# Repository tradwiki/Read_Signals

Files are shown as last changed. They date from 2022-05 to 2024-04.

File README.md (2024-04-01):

# rythm-visuals-plank-5
Podorythmic drawplank setup

rythm-visuals-plank-5 is an adaptation of [rythm-visuals-plank-4](https://github.com/tradwiki/rythm-visuals-plank-4). 
It transforms the reading of sensors embedded in a plank and transforms it into a midi and OSC signal to generate visuals.
This project showcases the use of analog piezo sensors and FSR sensors sending MIDI signals through a custom circuit that are translated in OSC through python and sent to a processing program to generate visuals.

## Getting started
* Connect the plank to the computer via USB.
* Run the script [analyse_signal.py](https://github.com/tradwiki/rythm-visuals-plank-5/blob/main/Analyse_signal/Analyse_signal.py)
* Run Drawplank 2.0 script.

## Planche 5 - Read_Signals (Arduino Script)
[Planche_5_-_Read_Signals](https://github.com/tradwiki/rythm-visuals-plank-5/tree/main/Planche_5_-_Read_Signals) is designed to be uploaded to a Teensy (3.6) controller via the arduino IDE (see [Teensyduino documentation](https://www.pjrc.com/teensy/teensyduino.html)). The script sends data through the serial port to notify of an analog value spike on specified pins when the polled value is above the baseline by a certain threshold. The baseline is averaged over the previous readings while they remain below threshold. The threshold is adjusted based on signal stability to allow for more sensitive readings with more stable sensors. The script also sends and/or receives MIDI signals across USB using Teensy built-in support (see [Teensy USB MIDI documentation](https://www.pjrc.com/teensy/td_midi.html)).

<code style="color: Darkorange;">The arduino script is downloaded once in the Teensy of the plank.</code> 
### Configuration
Modify [/Planche_5_-_Read_Signals/config.h](https://github.com/tradwiki/rythm-visuals-plank-5/blob/main/Planche_5_-_Read_Signals/config.h) to modify thresholds, delays, notes, pins, debug.
#### Considerations
* Midi pin values are specific to the circuit design as presented
* Analyse_Signal configurations are dependant of MIDI note configurations
* Drawplank 2.0 configurations are dependant of the Analyse_Signal configurations 
* Thresholds, baselines and delays are the result of physical tests on the plank and may vary for specific constructions

## Analyse Signal (Python script)
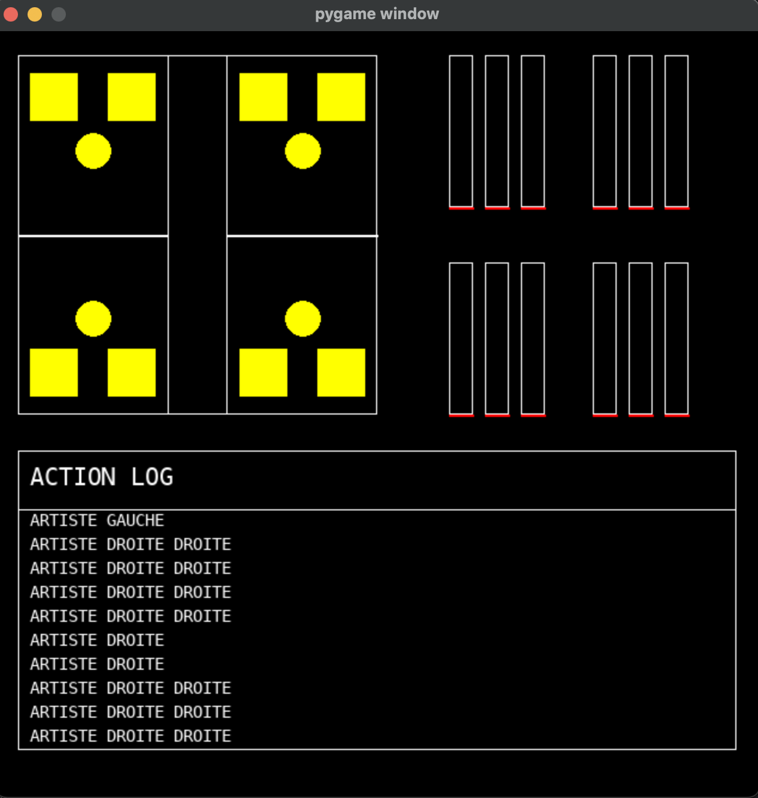
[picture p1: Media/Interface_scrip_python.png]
Analyse_signal screen capture


The python script translates MIDI signals coming from the plank to OSC signals. It interpretates different spikes and repetitions based on the signal received from the serial port as well as bpm.
The python script offers a visual interface of the incoming signals for troubleshooting through the pygame librairie.
### Configuration
[python_script/Sensor.py](https://github.com/tradwiki/rythm-visuals-plank-5/blob/main/Analyse_signal/Sensor.py) defines the OSC signal parameters as well as the sensor names.
By default, data is sent to the IP address 10.10.30.44 through port 5005.
#### Libraries for python
The installation of the following librairies is required for the python script.
* [python-osc](https://pypi.org/project/python-osc)
* [pygame](https://www.pygame.org/wiki/GettingStarted)

## Drawplank 2.0
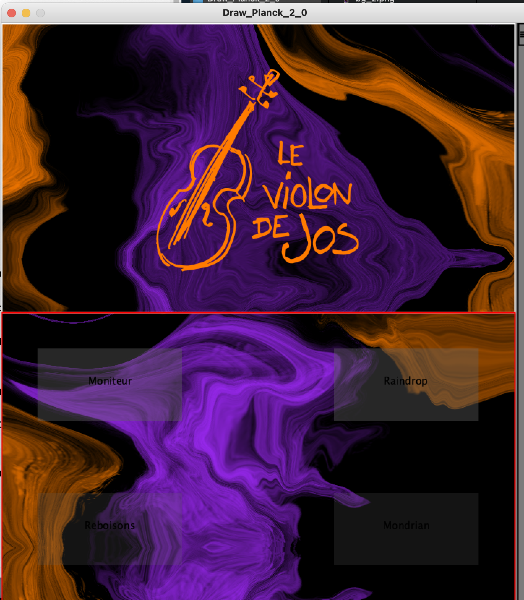
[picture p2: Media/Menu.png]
Drawplank screen capture

[Drawplank 2.0](https://github.com/tradwiki/rythm-visuals-plank-5/tree/main/DrawPlanck-2.0) was developped with the purpose of being used for video mapping through [Splash](https://sat.qc.ca/fr/splash/).
The program offers different modes of visual rendering of the plank's signal. 

<code style="color: Darkorange;">In order to use Drawplank 2.0, the python script must be running.</code> 
### Modes
Drawplank 2.0 offers 4 different modes
* Monitor
* Mondrian
* Raindrop
* Reboisons
### Use
* To select mode, the corresponding pad must be held.
* To exit a selected mode, the upper left pad must be held down.

## Device
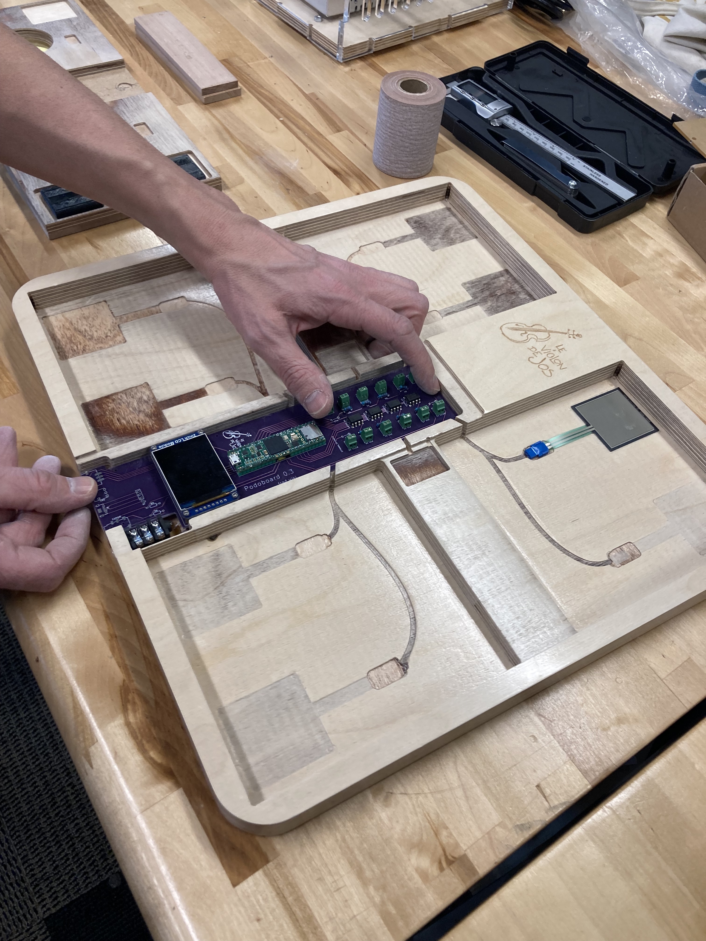
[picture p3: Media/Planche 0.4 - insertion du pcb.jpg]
Insertion of the pcb in the plank


A custom pcb was printed for this project. The circuit uses 8 FSR sensors and 5 Piezo sensors.
One piezo sensor is used as a surface microphone and does not produce a digital signal.
The plank was cut using a CNC.
Further discription is available in the [/circuit](https://github.com/tradwiki/rythm-visuals-plank-5/tree/main/Circuit) folder.

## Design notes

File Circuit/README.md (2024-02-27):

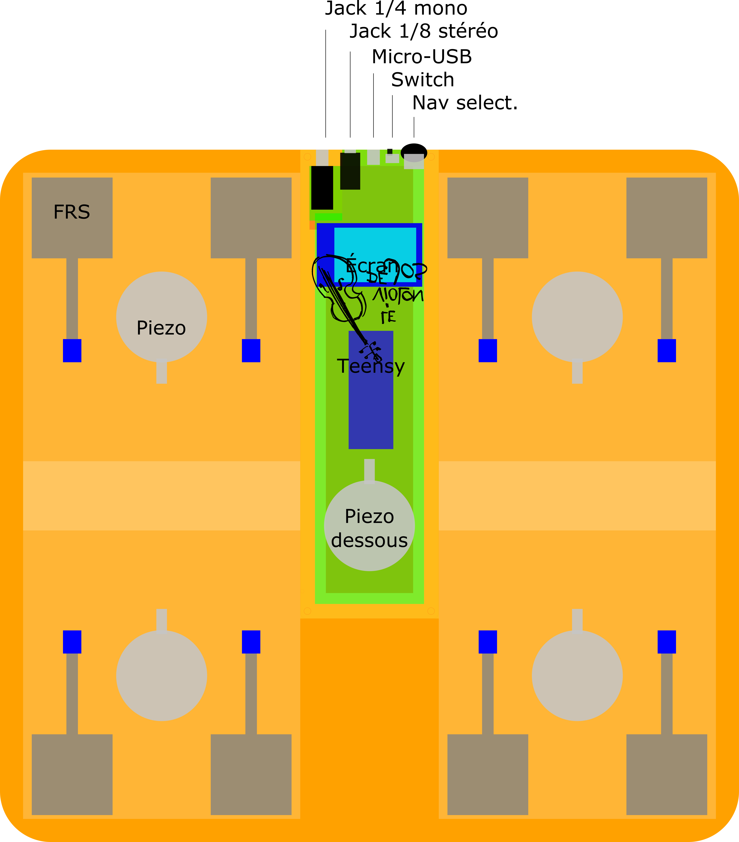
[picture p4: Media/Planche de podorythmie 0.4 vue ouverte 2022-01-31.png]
Plan planche de podorythmie


# Podoboard 0.3
The podoboard 0.3 is a custom printed pcb board that collects signals of 8 FSR sensors and 5 piezo sensors which were embedded in a Plank. The gerber files can be found in the [podoboard gerber](https://github.com/tradwiki/rythm-visuals-plank-5/tree/main/Circuit/podoboard%20gerber) folder.

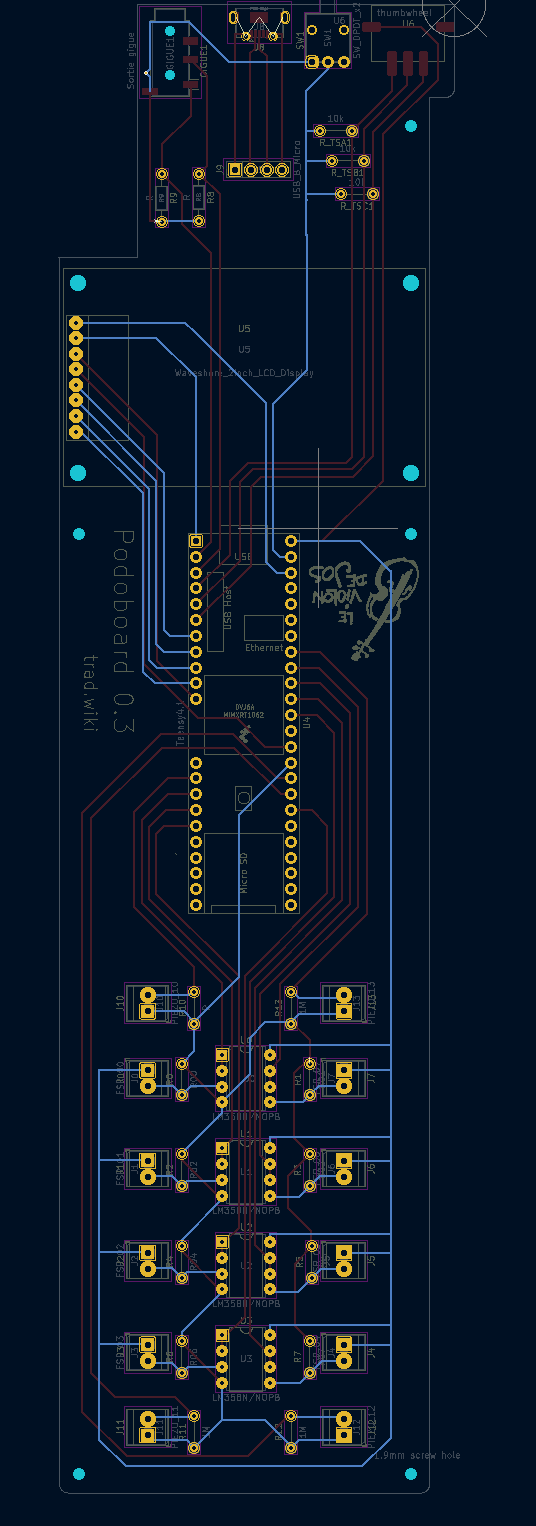
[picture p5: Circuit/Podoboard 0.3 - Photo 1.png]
Podoboard 0.3


### List of parts
* [Teensy 3.6](https://www.pjrc.com/store/teensy36.html)
* [FSR Sensor](https://www.sparkfun.com/products/9376) * 8
* [Piezo Sensor](https://www.digikey.ca/en/products/detail/7BB-35-3C/490-7716-ND/4358156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)
* [LM358P Amplifier](https://www.digikey.ca/en/products/detail/LM358P/296-1395-5-ND/277042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) * 5
* [SBL5100 Schottky diode](https://www.digikey.ca/en/products/detail/SBL5100TA/1655-1527-1-ND/6022972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) * 8
* 5 kOhm Resistor * 5
* [FSR Amplhenol 2.54 mm connectors](http://d.digikey.com/dc/mn-w0iJh4uEE_bUitNCuXsaMqkw5UctQEQXQivOAnBOQnPRuGl71VF0ow_3mKzthT57jIPNeUOJXfLLS_QA7CxnVzpsYQBHfvLHpVdyEOlp4vdeCMniPBPFYAcDw0YV2FBJ9wsG8VWLjt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) * 8
* [Screw terminals](https://www.digikey.ca/en/products/detail/OSTVN02A150/ED10561-ND/1588862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) *   13

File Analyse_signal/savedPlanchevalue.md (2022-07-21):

color C1 = color(150, 30, 0);
int NUM_FSR = 8;
int NUM_PIEZO = 4;
int SENSOR_STORED_READ_SIZE = 400;

int FSR_STATE_THRESHOLD = 10;
int PIEZO_STATE_THRESHOLD = 10;
int PLEIN_PIED_THRESHOLD = 10;
int PLEIN_PIED_MEAN = 50;
int FSR_MAX_TIME = 3000;
int PIEZO_MAX_TIME = 3000;

int[] FSR_NOTES = {74, 76, 78, 79, 81, 83, 85, 86};
int[] PIEZO_NOTES = {100, 101, 102, 103};

//int FSR_GRAPH_WIDTH = 350;
int MAX_BAR_TIME = 3000;

class Sensor {
  int id, note;
  String type;
  boolean state;
  int read, max;
  PFont font;
  int timer;
  int stateThreshold, maxTime;
  int[] storedReads;
  int readIndex;

  Sensor(String type, int id, int note) {
    this.type = type;
    this.id = id;
    this.note = note;
    this.read = 0;
    this.state = false;
    this.font = createFont("Noto Serif", 14);
    this.storedReads = new int[SENSOR_STORED_READ_SIZE];
    this.readIndex = 0;

    if (type == "fsr") {
      this.stateThreshold = FSR_STATE_THRESHOLD;
      this.maxTime = FSR_MAX_TIME;
    } else {
      this.stateThreshold = PIEZO_STATE_THRESHOLD;
      this.maxTime = PIEZO_MAX_TIME;
    }
  }

  int getRead() {
    return this.read;
  }

  void advanceRead() {
    storedReads[readIndex] = read;
    readIndex = (readIndex + 1) % SENSOR_STORED_READ_SIZE;
  };

  void setRead(int r) {

  }
  
  void handleOSC(OscMessage theOscMessage){
    if (!(theOscMessage.addrPattern().equals(this.prevTap))) {
      this.prevTap = theOscMessage.addrPattern();

      int x, y;
      
      switch(prevTap) {
      case "/FSR/PG":
        x = int(random(0, screenWidth / 2));
        y = int(random(0, screenHeight / 2));
        break;
      case "/FSR/PD":
        x = int(random(screenWidth / 2, screenWidth));
        y = int(random(0, screenHeight / 2));
        break;
      case "/FSR/AG":
        x = int(random(0, screenWidth / 2));
        y = int(random(screenHeight/ 2, screenHeight));
        break;
      case "/FSR/AD":
        break;
      default:
      }
    }
  }

  void showGraph(int x, int y, float graphX, int w, int h) {
    noStroke();
    textFont(font);
    fill(255);
    text(type + id, x - 30, y + h);
    //noFill();
    //strokeWeight(2);
    fill(255);
    rectMode(CORNER);
    rect(x, y, w, h);
    float graphY;
    fill(C1);
    noStroke();

    for (int i = 0; i < readIndex; i++) {
      graphY = map(storedReads[i], 0, 127, 0, h - 5);
      rect(x + i * 2, y - 2 - graphY + h, 2, 2);
    }
  }

  void showGraph2(int x, int y, float graphX, int w, int h) {
    noStroke();
    fill(255);
    rectMode(CORNER);
    rect(x, y, SENSOR_STORED_READ_SIZE * 2, h);
    float graphY;
    fill(C1);
    noStroke();

    for (int i = 0; i < 400; i++) {
      graphY = map(storedReads[i], 0, 127, 0, h - 5);
      rect(x + i * 2, y - 2 - graphY + h, 2, graphY);
    }

    fill(C1);
    rect(x + readIndex * 2, y, 5, 35);
  }

  void showGraph3(int x, int y, float graphX, int w, int h) {
    noStroke();
    textFont(font);
    fill(255);
    text(type + id, x - 30, y + h);
    //noFill();
    //strokeWeight(2);
    fill(255);
    rectMode(CORNER);
    rect(x, y, SENSOR_STORED_READ_SIZE * 2, h);
    float graphY;
    fill(0, 123, 0);
    noStroke();

    for (int i = readIndex / 2; i < readIndex; i++) {
      graphY = map(storedReads[i], 0, 127, 0, h - 5);
      rect(x + i * 2, y - 2 - graphY + h, 2, graphY);
    }

    //fill(255, 255, 255);
    rect(x + readIndex * 2, y, 2, 70);
  }

  void showBar(int x, int y) {
    rectMode(CORNER);
    noStroke();
    fill(255);
    int size = 100;
    rect(x, y, 20, size);
    fill(0, 255, 0);
    float level = map(read, 0, 127, 0, size);
    rect(x, y - level + size, 20, level);
    stroke(255);
    //stroke(0);
    fill(C1);
    float mappedMax = map(max, 0, 127, 0, size);
    noStroke();
    rect(x, y - mappedMax + size, 20, 3);
    if (millis() - this.timer > maxTime && max > 1) {
      max = 1;
    }
  }

  void emptyStoreReads() {
    for (int i = 0; i < SENSOR_STORED_READ_SIZE; i++) {
      storedReads[i] = 0;
    }
  }
}

class Planche {
  //OscP5 oscP5;
  Sensor[] fsr;
  Sensor[] piezo;
  Sensor[] sGauche, sDroite;
  float graphX;
  boolean pauseGraph, pauseBar;
  float mean;
  PFont font;

  Planche() {
    //this.oscP5 = new OscP5(this, 1100);
    print(PFont.list());
    this.font = createFont("Noto Serif", 14);
    this.pauseGraph = false;
    this.pauseBar = false;
    this.fsr = new Sensor[NUM_FSR];
    this.piezo = new Sensor[NUM_PIEZO];
    this.sGauche = new Sensor[6];
    this.sDroite = new Sensor[6];
    this.mean = 0;

    for (int i = 0; i < NUM_FSR; i++) {
      fsr[i] = new Sensor("fsr", i, FSR_NOTES[i]);
    }

    for (int i = 0; i < NUM_PIEZO; i++) {
      piezo[i] = new Sensor("piezo", i, PIEZO_NOTES[i]);
    }

    for (int i = 0; i < 4; i++) {
      sGauche[i] = fsr[i];
      sDroite[i] = fsr[i + 4];
    }

    for (int i = 0; i < 2; i ++) {
      sGauche[i + 4] = piezo[i];
      sDroite[i + 4] = piezo[i + 2];
    }
  }

  void showGrid(int x, int y) {
    fill(255);
    textFont(font);
    textAlign(LEFT);
    //text("Senseurs actifs", x - 150, y - 160);
    rectMode(CENTER);
    stroke(255);
    noFill();
    rect(x, y, 300, 300);
    strokeWeight(2);
    stroke(255);
    noFill();
    rect(x - 75, y - 75, 150, 150);
    rect(x + 75, y - 75, 150, 150);
    rect(x - 75, y + 75, 150, 150);
    rect(x + 75, y + 75, 150, 150);

    for (int i = 0; i < fsr.length; i++) {

      float tempX = x - 185 + 70 * (i % 4 + 1);
      float tempY = y - 110;

      if ((i > 1 && i < 4) || (i > 5)) {
        tempX += 20;
      }

      if (i >= 4) {
        tempY = y + 110;
      }

      noStroke();
      fill(255);
      rect(tempX, tempY, 50, 50);
      fill(255, 255 - map(fsr[i].read, 0, 127, 0, 255), 0);
      rect(tempX, tempY, map(fsr[i].read, 0, 127, 0, 50), map(fsr[i].read, 0, 127, 0, 45));
    }

    for (int i = 0; i < piezo.length; i++) {
      float tempX = x - 80 + 160 * (i % 2);

      float tempY = y  - 50;

      if (i >= 2) {
        tempY = y + 50;
      }
      fill(255);
      ellipse(tempX, tempY, 50, 50);
      fill(255, 255 - map(piezo[i].read, 0, 127, 0, 255), 0);
      ellipse(tempX, tempY, map(piezo[i].read, 0, 127, 0, 50), map(piezo[i].read, 0, 127, 0, 50));
    }
    
        if (padComplet(fsr[0], fsr[1])) {
      fill(255, 255, 0);
      noStroke();
      rect(x - 75, y - 100, 130, 50);
      fill(0);
      textAlign(CENTER);
      text("Public cour", x - 75, y - 100);
    }

    if (padComplet(fsr[2], fsr[3])) {
      fill(255, 255, 0);
      noStroke();
      rect(x + 75, y - 100, 130, 50);
      fill(0);
      textAlign(CENTER);
      text("Public jardin", x + 75, y - 100);
    }

    if (padComplet(fsr[4], fsr[5])) {
      fill(255, 255, 0);
      noStroke();
      rect(x - 75, y + 100, 130, 50);
      fill(0);
      textAlign(CENTER);
      text("Artiste cour", x - 75, y + 100);
    }

    if (padComplet(fsr[6], fsr[7])) {
      fill(255, 255, 0);
      noStroke();
      rect(x + 75, y + 100, 130, 50);
      fill(0);
      textAlign(CENTER);
      text("Artiste jardin", x + 75, y + 100);
    }

    if (piedPlein(sGauche)) {
      fill(255, 255, 0);
      noStroke();
      rect(x - 78, y, 100, 100);
      fill(0);
      textAlign(CENTER);
      text("Pied plein gauche", x - 100, y);
    }

    if (piedPlein(sDroite)) {
      fill(255, 255, 0);
      noStroke();
      rect(x + 75, y, 100, 100);
      fill(0);
      textAlign(CENTER);
      text("Pied plein droite", x + 75, y);
    }
  }

  void restartGraph(int x, int y, int w, int h) {
    fill(123);
    //stroke(0, 255, 0);
    rectMode(CENTER);
    graphX = 0;
    rect(x, y, w, 75 * NUM_FSR + 100);

    //for (int i = 0; i < NUM_FSR; i++ ) {
    //  fsr[i].emptyStoreReads();
    //}
  }

  boolean piedPlein(Sensor[] cote) {
    this.mean = 0;
    for (int i = 0; i < 6; i++) {
      this.mean = cote[i].getRead();
    }
    mean = mean / 6;
    boolean c1 = cote[4].read > PLEIN_PIED_THRESHOLD;
    boolean c2 = cote[5].read > PLEIN_PIED_THRESHOLD;
    boolean c3 = mean > PLEIN_PIED_MEAN;
    return c1 && c2 && c2;
  }

  void showGraph(int x, int y, int w, int h) {
    fill(255);
    textAlign(LEFT);
    //text("Signal dans le temps", x, y - 30);
    if (!pauseGraph) {
      graphX++;

      if (graphX > w) {
        restartGraph(x, y, w, h * 8);
        //planche.restartGraph(width / 2, height / 2, GRAPH_WIDTH, GRAPH_HEIGHT);
      }

      for (int i = 0; i < NUM_FSR; i++) {
        fsr[i].advanceRead();
        fsr[i].showGraph2(x, y + i * ( h + 30), graphX, w, h);
      }
    } else {
      if (mouseX > x - 30 && mousePressed) {
        strokeWeight(1);
        stroke(255, 0, 0);
        line(x, mouseY, width - 10, mouseY);
        line(mouseX, y - 10, mouseX, height - 10);
      }
    }
  }

  void handleNote(int note, int velocity) {

    for (int i = 0; i < NUM_FSR; i++) {
      if (note == fsr[i].note) {
        fsr[i].setRead(velocity);
        //fsr[i].sendOsc();
      }
    }

    for (int i = 0; i < NUM_PIEZO; i++) {
      if (note == piezo[i].note) {
        piezo[i].setRead(velocity);
      }
    }
  }

  void showBar(int x, int y) {
    fill(255);
    textAlign(LEFT);
    text("Niveaux senseurs", x, y - 10);
    if (!pauseBar) {
      int tempX, tempY;

      for (int i = 0; i < NUM_FSR; i++) {
        tempY = y;
        tempX = x + i % 4 * 80;

        if (i > 3) {
          tempY = y + 173;
        }

        fsr[i].showBar(tempX, tempY);
      }

      for (int i = 0; i < NUM_PIEZO; i++) {
        tempY = y;
        tempX = x + i % 2 * 160 + 40;

        if (i > 1) {
          tempY = y + 173;
        }
        piezo[i].showBar(tempX, tempY);
      }
    }
  }

  void showBarVertical(int x, int y) {
    fill(255);
    textAlign(LEFT);
    text("Niveaux senseurs", x, y - 20);
    if (!pauseBar) {
      int tempX, tempY;
      for (int i = 0; i < NUM_FSR; i++) {
        tempY = y;
        tempX = x + i * 80;

        fsr[i].showBar(tempX, tempY);
      }

      for (int i = 0; i < NUM_PIEZO; i++) {
        tempY = y;
        tempX = x + i * 160 + 40;
        piezo[i].showBar(tempX, tempY);
      }
    }
  }

  void showInterpret(int x, int y) {
    fill(255);
    //text("Signal interpreté", x - 150, y - 170);
    rectMode(CENTER);
    fill(0);
    noStroke();
    rect(x, y, 300, 300);
    strokeWeight(2);
    stroke(255);
    noFill();
    rect(x - 75, y - 75, 150, 150);
    rect(x + 75, y - 75, 150, 150);
    rect(x - 75, y + 75, 150, 150);
    rect(x + 75, y + 75, 150, 150);

    if (padComplet(fsr[0], fsr[1])) {
      fill(255, 255, 0);
      noStroke();
      rect(x - 75, y - 100, 130, 50);
      fill(0);
      textAlign(CENTER);
      text("Public gauche", x - 75, y - 100);
    }

    if (padComplet(fsr[2], fsr[3])) {
      fill(255, 255, 0);
      noStroke();
      rect(x + 75, y - 100, 130, 50);
      fill(0);
      textAlign(CENTER);
      text("Public droite", x + 75, y - 100);
    }

    if (padComplet(fsr[4], fsr[5])) {
      fill(255, 255, 0);
      noStroke();
      rect(x - 75, y + 100, 130, 50);
      fill(0);
      textAlign(CENTER);
      text("Artiste gauche", x - 75, y + 100);
    }

    if (padComplet(fsr[6], fsr[7])) {
      fill(255, 255, 0);
      noStroke();
      rect(x + 75, y + 100, 130, 50);
      fill(0);
      textAlign(CENTER);
      text("Artiste droite", x + 75, y + 100);
    }

    if (piedPlein(sGauche)) {
      fill(255, 255, 0);
      noStroke();
      rect(x - 78, y, 100, 100);
      fill(0);
      textAlign(CENTER);
      text("Pied plein gauche", x - 100, y);
    }

    if (piedPlein(sDroite)) {
      fill(255, 255, 0);
      noStroke();
      rect(x + 75, y, 100, 100);
      fill(0);
      textAlign(CENTER);
      text("Pied plein droite", x + 75, y);
    }
  }

  void mur2(int x, int y) {
    if (!pauseBar) {
      int tempX, tempY;
      //for (int i = 0; i < NUM_FSR; i++) {
      //  tempY = y + 290;
      //  tempX = x + i * 80  + 100;
      //  fsr[i].showBar(tempX, tempY);
      //}
      tempY = y + 290;
      tempX = x + 80 - 30;
      fsr[0].showBar(tempX, tempY);
      tempX = x + 160 - 30;
      fsr[1].showBar(tempX, tempY);
      tempX = x + 240 - 30;
      fsr[2].showBar(tempX, tempY);
      tempX = x + 320 - 30;
      fsr[3].showBar(tempX, tempY);
      tempX = x + 380 + 60;
      fsr[6].showBar(tempX, tempY);
      tempX = x + 460 + 60;
      fsr[7].showBar(tempX, tempY);
      tempX = x + 580 + 60;
      fsr[4].showBar(tempX, tempY);
      tempX = x + 660 + 60;
      fsr[5].showBar(tempX, tempY);

      //for (int i = 0; i < NUM_PIEZO; i++) {
    //  tempY = y + 290;
    //  tempX = x + i * 160 + 40 + 100;
    //  piezo[i].showBar(tempX, tempY);
    //}
    tempY = y + 290;
    tempX = x + 120 - 30;
    piezo[0].showBar(tempX, tempY);
    tempX = x + 280 - 30;
      piezo[1].showBar(tempX, tempY);
    tempX = x + 420 + 60;
    piezo[3].showBar(tempX, tempY);
    tempX = x + 620 + 60;
    piezo[2].showBar(tempX, tempY);
    //}
  }

  if (!pauseGraph) {

    int w = 800;
    int h = 30;
    graphX++;

    if (graphX > w) {
      restartGraph(x, y, w, h * 8);
      //planche.restartGraph(width / 2, height / 2, GRAPH_WIDTH, GRAPH_HEIGHT);
    }

    for (int i = 0; i < NUM_FSR; i++) {
      fsr[i].advanceRead();
      fsr[i].showGraph2(x, y + i * ( h + 5), graphX, w, h);
    }
  }
}

boolean padComplet(Sensor p1, Sensor p2) {
  return p1.state && p2.state;
}

boolean glissementVerticalAvant(Sensor[] cote) {
  boolean c = false;

  return c;
}
}

float getMean(Sensor[] s) {
  for (int i = 0; i < s.length; i++) {
    println(s[i].read);
  }
  return 0;
<!-- } -->

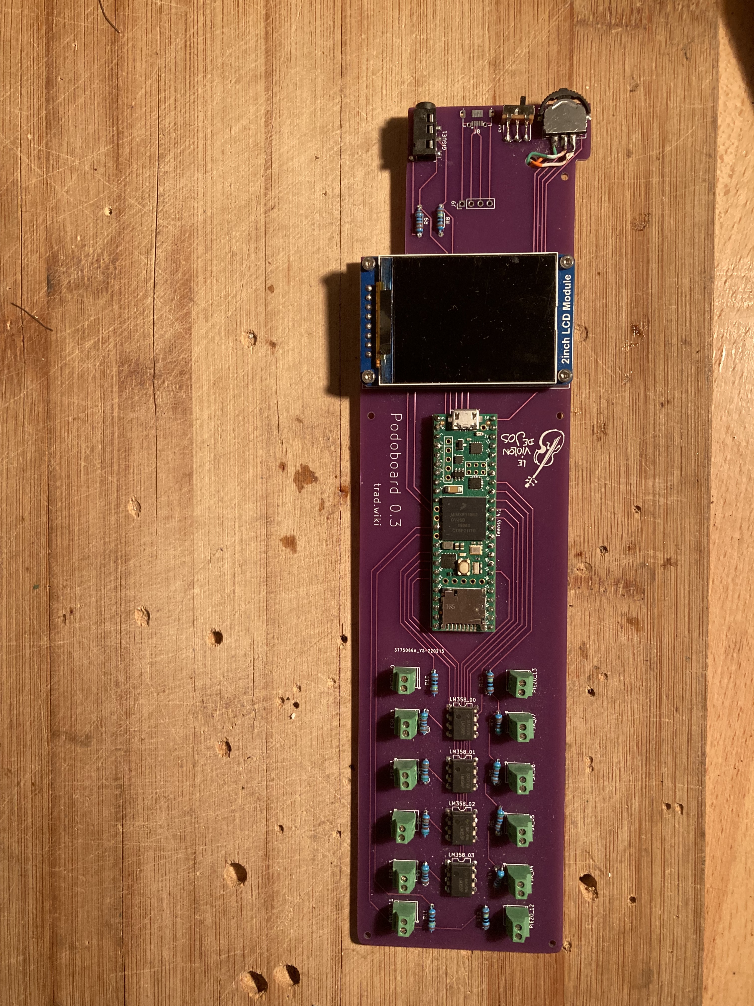
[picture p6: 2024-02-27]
Media/Podoboard - Photo 3.jpg

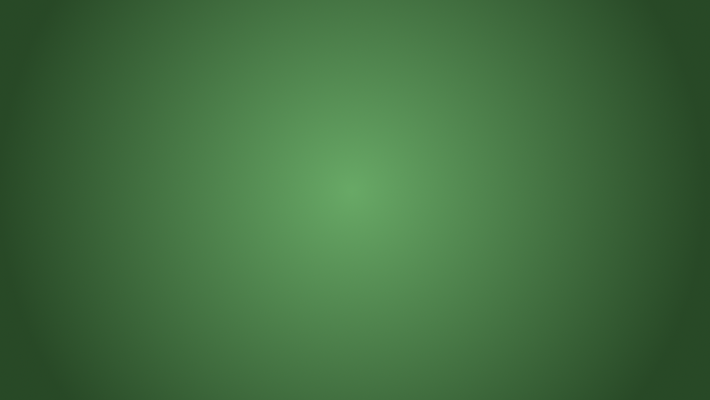
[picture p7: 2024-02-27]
DrawPlanck-2.0/Draw_Planck_2_0/grass_floor.png

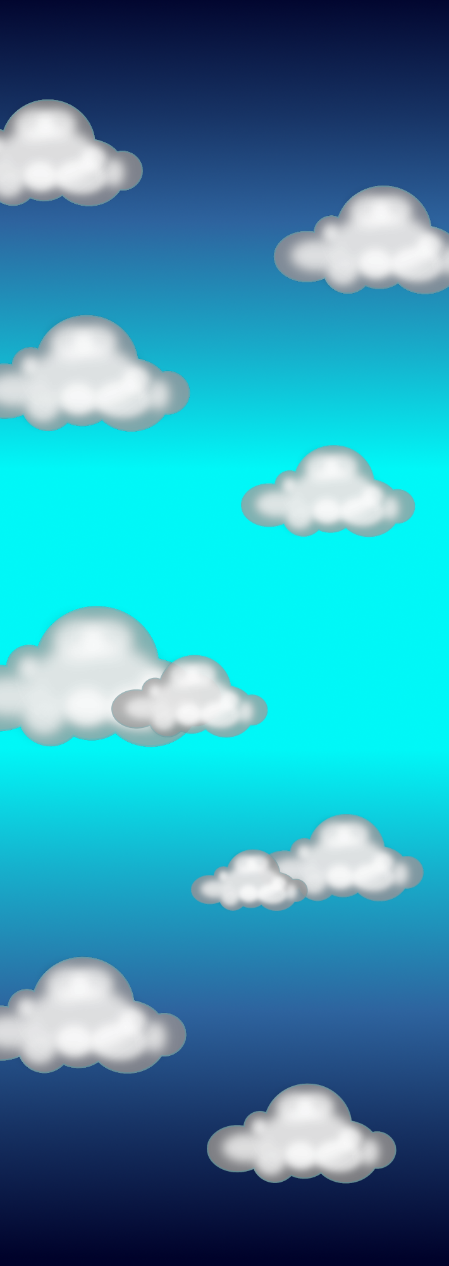
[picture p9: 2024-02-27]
DrawPlanck-2.0/Draw_Planck_2_0/menu_ciel.png

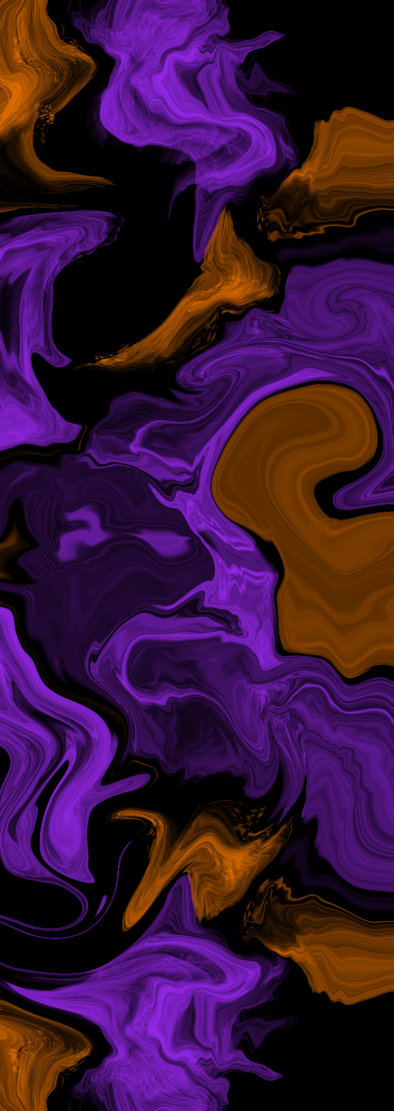
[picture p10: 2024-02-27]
DrawPlanck-2.0/Draw_Planck_2_0/bg_2.png

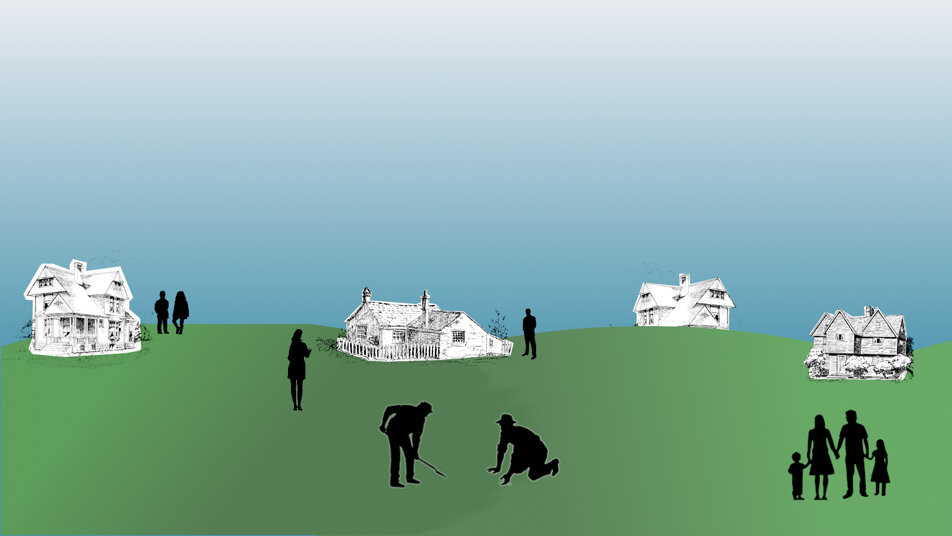
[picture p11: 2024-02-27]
DrawPlanck-2.0/Draw_Planck_2_0/Tree_bg.png

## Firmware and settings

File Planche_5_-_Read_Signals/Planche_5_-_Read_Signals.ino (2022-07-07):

#include <limits.h>
#include "config.h"
#include "FSR.h"
#include "Piezo.h"
#include "Motor.h"



FSR* FSR_GRID[NUM_FSR_SENSORS];
Piezo* PIEZO_GRID[NUM_PIEZO_SENSORS];
Pad* PAD_GRID[NUM_PADS];
//  motorSetup(MOTOR_GRID);
void setup() {
  Serial.begin(9600);
  Serial.println("Welcome to read signals");
  fsrSetup(FSR_GRID, FSR_SENSOR_PINS, FSR_NOTES_1);
  piezoSetup(PIEZO_GRID, PIEZO_SENSOR_PINS, PIEZO_NOTES);

  if (MIDI_MODE == 0) {
    padSetup(PAD_GRID, FSR_GRID, FSR_NOTES_0);
  }
}

void loop() {

//  fsrPrintReadInRows(FSR_GRID);

  if (MIDI_MODE == 0) {
    fsrRead(FSR_GRID);
    padRead(PAD_GRID);
  }

  else if (MIDI_MODE == 1) {
    piezoRead(PIEZO_GRID);
    piezoPrintReadInRows(PIEZO_GRID);

    fsrRead(FSR_GRID);
    fsrPrintReadActive(FSR_GRID);
    sendFSRMidi(FSR_GRID);
  }

  //  readExternalMidi(MOTOR_GRID);
  //  FSRtoMotor(FSR_GRID, MOTOR_GRID);
  delay(10);
}

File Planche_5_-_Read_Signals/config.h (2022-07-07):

#pragma once
const bool DEBUG = false;
const bool FSR_DEBUG = true;
const bool PIEZO_DEBUG = true;
const bool MIDI_RECEIVE_DEBUG = true;
const bool WITH_MIDI = true;

// Différents modes
// 0 - Mode 4 notes fsr
// 1 - Mode 8 notes fsr
const int MIDI_MODE = 1;

const int BAUD_RATE = 9600;
const int MIDI_CHANNEL = 1;
bool WITH_MIDI_INPUT = true;
bool WITH_MIDI_OUTPUT = true;


const unsigned long MICROSECOND = 1;
const unsigned long MILLISECOND = 1000;
const unsigned long SECOND = 1000000;
const int PRINT_DELAY = 50 * MICROSECOND;

const int LED_PIN = 13;

// FSR VALUES
const bool READ_RESISTANCE = true;
const static int NUM_FSR_SENSORS = 8;
const static int NUM_PADS = 4;
const int FSR_SENSOR_PINS[] = {25, 26, 27, 39, 15, 16, 17, 18};
const int FSR_NOTES_0[] = {84, 80, 82, 85};
const int FSR_NOTES_1[] = {74, 76, 81, 83, 85, 86, 79, 78};

// FSR thresholds
const int FSR_MAX_READING = 1023;
const int FSR_MIN_THRESHOLD = 100;
const int FSR_MAX_THRESHOLD = 150;
const int FSR_MIN_JUMPING_RANGE = 80;

// FSR CONST
static const int BASELINE_BUFFER_SIZE = 400;
unsigned const long NOTE_VELOCITY_DELAY = 2 * MILLISECOND;
unsigned const long NOTE_ON_DELAY = 50 * MILLISECOND;
unsigned const long NOTE_OFF_DELAY = 50 * MILLISECOND;
unsigned const long SUSTAIN_DELAY = 100 * MILLISECOND;
unsigned const long BASELINE_SAMPLE_DELAY = 0.5 * MILLISECOND;
unsigned const long BASELINE_BLOWBACK_DELAY = 40 * MILLISECOND;
const int RETRO_JUMP_BLOWBACK_SAMPLES = (0.5 * MILLISECOND) / BASELINE_SAMPLE_DELAY;
const int MAX_CONSECUTIVE_SUSTAINS = (10 * SECOND) / SUSTAIN_DELAY;


// PIEZO VALUES
const static int NUM_PIEZO_SENSORS = 4;
const int PIEZO_SENSOR_PINS[] = {24, 19, 40, 41};
const int PIEZO_NOTES[] = {100, 101, 102, 103};
const int MAX_PIEZO_TIME = 10;

// MOTOR VALUES
const int TAPS_PER_PULSE = 1;
const bool WITH_MOTORS = true;
const int NUM_MOTORS = 2;
const int MOTOR_PINS[NUM_MOTORS] = {1, 2};
const int SENSOR_TO_MOTOR[] = {1, 1, -1, -1, -1, -1, -1, -1};
const int MOTOR_NOTES[2][2] = {{74, 76}, {79, 78}};
unsigned const long MAX_MOTOR_PULSE_DURATION = 400 * MILLISECOND;
unsigned const long MAX_MOTOR_PULSE_BREAK = 400 * MILLISECOND;
const int MOTOR_THRESHOLD = 20;

//External Midi
unsigned long lastExternalMidiOn[NUM_FSR_SENSORS];

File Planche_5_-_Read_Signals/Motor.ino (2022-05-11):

#include "Motor.h"
#include "FSR.h"

Motor::Motor() {}

Motor::Motor(const int pin, const int* notes, const int index) {
  PIN = pin;
  NOTES = notes;
  INDEX = index;
  state = "OFF";
}

Motor& Motor::operator=(const Motor&) {
  return *this;
}

int Motor::getPin() {
  return PIN;
}

const int* Motor::getNotes() {
  return NOTES;
}

int Motor::getIndex() {
  return INDEX;
}

String Motor::getState() {
  return state;
}

void Motor::motorOn() {
  pinMode(PIN, OUTPUT);
  digitalWrite(PIN, HIGH);
  state = "ON";
}

void Motor::motorOff() {
  pinMode(PIN, OUTPUT);
  digitalWrite(PIN, LOW);
  state = "OFF";
}

void Motor::receiveNote(int note, int value) {
  bool rightNote = false;

  for (int i = 0; i < NUM_NOTES; i++) {
    if (NOTES[i] == note) {
      rightNote = true;
    }
  }

  if (rightNote) {
    if (state == "OFF" && value > MOTOR_THRESHOLD) {
      Serial.print("MOTOR ");
      Serial.print(INDEX);
      Serial.println(" TURNED ON");
      motorOn();
    }

    if (state == "ON" && value < MOTOR_THRESHOLD) {
      Serial.print("MOTOR ");
      Serial.print(INDEX);
      Serial.println(" TURNED OFF");
      motorOff();
    }
  }
}

void Motor::update() {
  //limiter so the motor doesn't stay on too long
  if ((millis() - timeStamp) >= MAX_MOTOR_PULSE_DURATION) {
    motorOff();
    timeStamp = millis();
  }
}

void Motor::printNotes() {
  for (int i = 0; i < NUM_NOTES; i++) {
    Serial.print(NOTES[i]);
  }
  Serial.println();
}

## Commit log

2022-03-17 initial commit
    Transfer de fichiers dans git
2022-03-24 Update FSR class
    sending notes but I am not getting the velocity
2022-04-27 Added "ROGUE" state for piezo sensors
2022-06-16 Updated visuals to work with splah
    Reconfiguration de l'espacement pour que ca fonctionne avec splash
2022-06-20 Ajustements pour la rencontre
    Emplacement des éléments pour la rencontre
2022-07-14 Added drawplanck 2.0
    Nouvelle interface graphique pour les visuels qui lis les signaux osc
2022-07-19 updated what osc signals are sent
    sends an off switch
2024-02-27 Refactor nomenclature
    - Enlever les fichiers/dossiers inutiles
    - Changement de nomenclature de dossiers
2024-02-27 Added media and circuit files
    [Podoboard_0.3-B_Cu.gbr, Podoboard_0.3-B_Mask.gbr, Podoboard_0.3-B_Paste.gbr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]
2024-02-27 Create README.md
    added a specific read me for the circuit
